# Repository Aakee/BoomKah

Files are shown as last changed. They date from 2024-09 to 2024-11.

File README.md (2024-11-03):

# Boom Kah
A *Keep Talking and Nobody Explodes* -inspired game with Arduino hardware.

Originally made for Hupsis-Punkku 2024 scouting competition.

## Overview

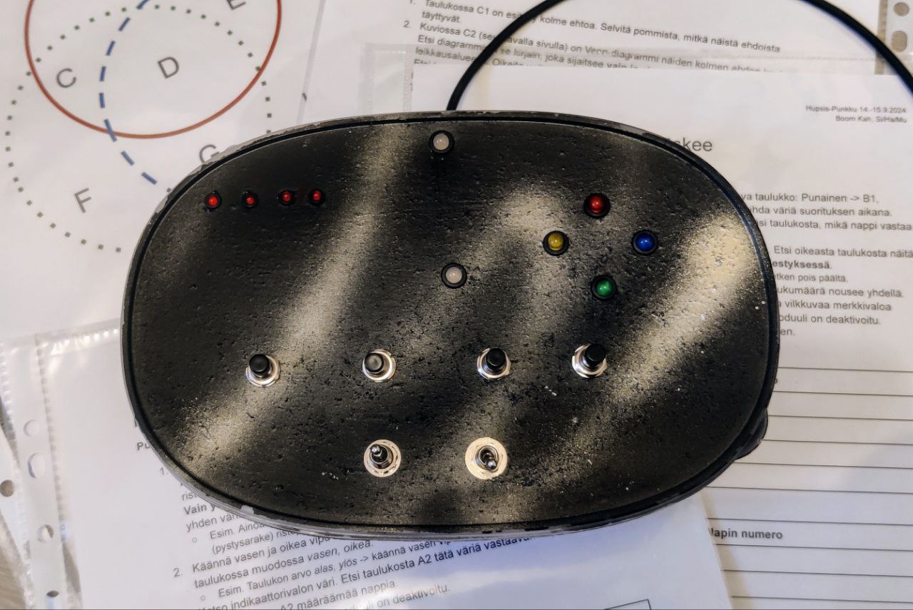
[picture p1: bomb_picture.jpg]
Bomb picture


Boom Kah is a game for two players. The objective is to co-operatively defuse a bomb, using a bomb defusal guide and the information given by the bomb.

The first player is a bomb defusal _Expert_. **The good news:** they have in hand all the information needed to defuse the bomb, in the form of a detailed Bomb Defusal Guide. **The bad news:** the bomb is not handled by them but by the second player, a total _Novice_ to bombs, who just happened to be in the wrong place in the wrong time (i.e. in a room with a bomb). 

Using voice as their only form of communication, the two players must communicate their through the bomb's modules, and hopefully not exploding in the process.

## Playing the game

### Defusal manual

Fear not, as the Expert has the access to the extensive Bomb Defusal Guide! The Guide is found in /docs, or [here](/docs/Pomminpurkuohjeet.pdf). For Expert eyes only -- the Novice is not allowed to see the manual while playing the game!

The Guide is only in Finnish for now.

### The Bomb

Below is a schematic figure and a photo of The Bomb.

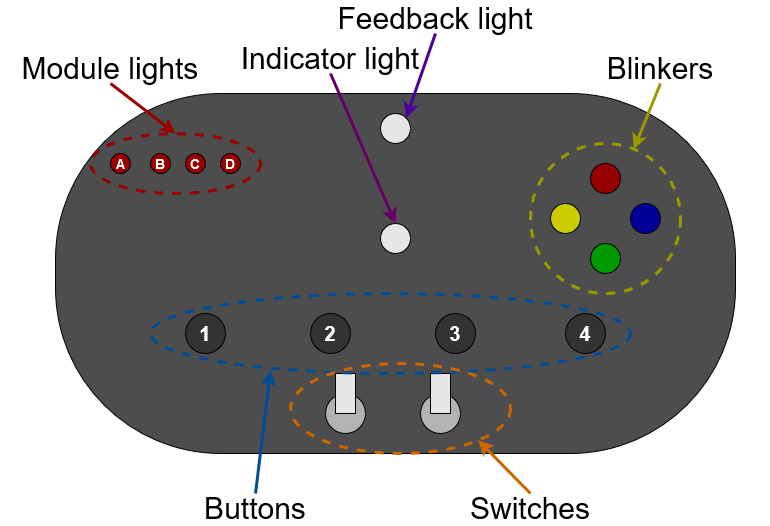
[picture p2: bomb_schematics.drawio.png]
Bomb schematics


The Bomb has four modules, each with their own set of deactivation rules. The current module to be deactivated can be determined by the **module lights**.

The Bomb gives information to the Novice in the form of **indicator light** and **blinker lights**. The Novice can then give commands to the bomb via the four buttons, conveniently called **buttons 1 - 4**, and two switches with three positions each, called **the left and the right switch**.

The Expert is not allowed to see The Bomb while playing. And while the Novice should only give such commands to The Bomb that the Expert reads from the manuals, it can happen that something is misunderstood... The Bomb gives feedback to the playes in the form of the **feedback light**: green light for correct actions, and red light for wrong actions. A high- or low-pitched beeping sound is also given alongside the feedback light: high for correct actions, and low for wrong actions.

The Bomb won't accept new commands while the feedback light is red. Initially, the time is rather short. However, this cooldown time gradually gets longer if the Novice gives too many incorrect inputs to the bomb.

### Defusing The Bomb

The modules must be deactivated one by one. The bomb is defused once all the modules have been deactivated. To mark this, the bomb plays a triple beeping sound, and the feedback light is turned green. Phew!

### Detonating The Bomb...?!?

As it is now, The Bomb does not actually explode (nor even simulate it). The goal of the players is to defuse the bomb as quickly as possible, but there is no maximum time, nor does the bomb explode even if incorrect inputs are given to the bomb. 

(But the players can give themselves some house rules, e.g. maximum time is 5 minutes, and the bomb explodes immediately after one incorrect input. Or they can experiment with the bomb and its modules and take all the time they need. Whatever suits the players best!)

## Software and hardware

The game is programmed with C++ enhanced with Arduino libraries. At the heart of the Bomb is a Arduino Nano (or a suitable clone).

List of the electrical components and schematics of the electorics can be found in /hardware.

## Credits

Akseli Konttas 2024

## Licence

MIT License, included in this repository

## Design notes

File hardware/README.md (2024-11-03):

# Boom Kah - hardware

## Arduino

The device was designed and built for Arduino Nano. For the actual production, [Seeeduino Nano](https://wiki.seeedstudio.com/Seeeduino-Nano/) was used instead. All the coupling diagrams and software should work with Arduino Nano or any equivalent Arduino clone, though.

## PCB

No PCB was made for this version; rather, the components were soldered straight to the Seeeduino pins with the help of a bread board.

## Components

The following describes other components used in the project. The codes refer to the codes shown in the coupling diagram.

### Buttons
Codes: B1B, B2B, B3B, B4B

Opening push button (circuit is closed when the button is not pressed, and open when the button is pressed). If you use closing push button, you need to modify the code accordingly in switch_handler.cpp.

### Switches
Codes: SW1, SW2

Switches with three positions: on-off-on.

### Module leds
Codes: DMOD1, DMOD2, DMOD3, DMOD4

Standard 3mm RED LEDs.

### Blinker leds
Codes: DBLNKRED, DBLNKGRN, DBLNKBLU, BBLNKYLW

Standard 5mm LEDs with differing colors (red, blue, green, yellow).

### Indicator led (RGB)
Code: DRGB

A common anode RGB LED.
If you use a common anode RGB, you need to make the following changes:

- Couple the common foot (anode) of the RGB to ground instead of 5V
- Change the polarity in rgb_handler.cpp: now the colours are set as '255-value'. Change them to be just 'value'.

### Feedback LED (RG)
Code: DRG

A common cathode red-green LED.

### Piezo loudspeaker
Code: BZ1

### Resistors

The LEDs have one series resistor to limit the currency and, by extension, the LED brightness of each LED. The values were found empirically so that each LED would shine with a suitable brightness. If using some other LEDs, you may need to change the values of these.

- Module LEDs: 1 kohm (each)
- Red blinker LED: 1 kohm
- Green blinker LED: 10 kohm
- Blue blinker LED: 5 kohm
- Yellow blinker LED: 680 ohm
- RGB: 200 ohm (each)
- RG: 200 ohm (each)

The buttons and swithces have the following pull-up and pull-down resistors:

- Buttons 1-4: 10 kohm pull-up resistor (each)
- Switches 1 and 2: 10 kohm pull-down resistor (each), and 10 kohm pull-up resistor (each).

The piezo loudspeaker has ha 200 ohm resistor in series.

Refer to the coupling diagram for better view on the usage and function of each resistor.

## Pin layout

Refer to the coupling diagram for resistors and other coupling details.

- D0: Module led B
- D1: Module led A
- D2: Module led C
- D3: Module led D
- D4: Red blinker
- D5: RGB red
- D6: Green blinker
- D7: Blue blinker
- D8: Piezo loudspeaker
- D9: RGB blue
- D10: RGB green
- D11: Yellow blinker
- D12: RG green
- D13: RG red
- A0 - A3: Buttons 1 - 4
- A4 - A5: Switches 1 and 2
- A6: Unconnected; initialization of the random seed

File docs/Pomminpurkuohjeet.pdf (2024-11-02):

Hupsis-Punkku 14.-15.9.2024 Boom Kah, Si/Ha/Mu

# Pomminpurun yleisohjeet

Pommissa on neljä moduulia, jotka pitää purkaa yksi kerrallaan, järjestyksessä A-B-C-D. Pommista löytyy yksi moduulivalo jokaista moduulia kohti, ja aktiivinen, tällä hetkellä purettava moduuli selviää palavasta moduulivalosta. Alla on kuva, jossa on eritelty pommin eri osat.

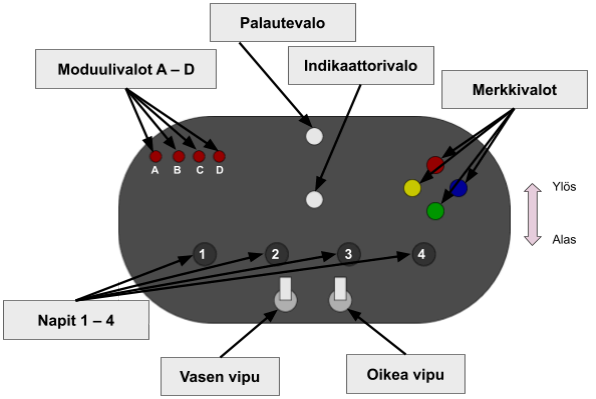
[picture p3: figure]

Purkuohjeet:
1. Katso, minkä moduulin valo palaa. Avaa oikean moduulin deaktivointiohjeet ja seuraa niitä.
- Merkkinä oikeista purkutoimenpiteistä pommi päästää korkeita piippauksia, ja palautevalo välähtää vihreänä.
- Merkkinä vääristä purkutoimenpiteistä pommi päästää matalan virheäänen, ja palautevalo syttyy punaisena. Pommi ei ota vastaan uusia komentoja, ennen kuin palautevalo on taas sammunut. Toistuvat virheet pidentävät aikaa, jona palautevalo palaa punaisena virheen jälkeen. Palautevalon sammuttua, jatka oikean moduulin deaktivointiohjeiden seuraamista.
2. Kun moduuli on deaktivoitu, kuulet kaksinkertaisen piippauksen ja seuraavan moduulin moduulivalo syttyy. Avaa tämän moduulin ohjeet ja seuraa niitä.
3. Kun kaikki moduulit A-D ovat deaktivoituja, kuulet kolminkertaisen piippauksen, kaikki moduulivalot sammuvat, ja palautevalo syttyy palamaan vihreänä. Pommi on nyt purettu onnistuneesti.

# Moduuli A: Vivut

Purkuohjeet:

1. Yksi tai kaksi merkkivaloa palaa.
Kahden merkkivalon palaessa etsi taulukosta A1 näiden kahden valon värien risteyskohdasta vipujen asennot.
Vain yhden merkkivalon palaessa etsi taulukosta A1 se kohta, joka on tämän yhden värin risteyskohdassa sekä vaaka- että pystyriviltä.
- Esim. Ainoastaan sininen valo palaa -> etsi taulukosta sinisen (vaakarivi) ja sinisen (pystysarake) risteyskohta (alas, ylös).
2. Käännä vasen ja oikea vipu taulukon A1 määräämään asentoon. Vivut ovat taulukossa muodossa vasen, oikea.
- Esim. Taulukon arvo alas, ylös -> käännä vasen vipu alas ja oikea vipu ylös
3. Katso indikaattorivalon väri. Etsi taulukosta A2 tätä väriä vastaavan napin numero.
4. Paina taulukon A2 määräämää nappia.
5. Toista kohtia 1-4, kunnes moduuli on deaktivoitu.

Taulukko A1

Punainen | Sininen | Vihreä | Keltainen
Punainen | Ylös, ylös | Ylös, keskelle | Keskelle, ylös | Alas, keskelle
Sininen | Ylös, keskelle | Alas, ylös | Alas, alas | Keskelle, keskelle
Vihreä | Keskelle, ylös | Alas, alas | Keskelle, alas | Ylös, alas
Keltainen | Alas, keskelle | Keskelle, keskelle | Ylös, alas | Alas, alas

Taulukko A2

Indikaattorivalon väri | Painettavan napin numero
Punainen | 3
Sininen | 1
Keltainen | 2
Turkoosi | 3
Violetti | 4
Valkoinen | 4
Vihreä | 1
Indikaattorivalo ei pala | 2

# Moduuli B: Kapteeni käskee

Purkuohjeet:

1. Katso indikaattorivalon väri ja etsi alta sitä vastaava taulukko: Punainen -> B1, sininen -> B2, ja vihreä -> B3. Indikaattorivalo ei vaihda väriä suorituksen aikana.
2. Yksi merkkivalo vilkkuu. Katso kohdassa 1 etsimästäsi taulukosta, mikä nappi vastaa kyseistä merkkivaloa. Paina tätä nappia.
3. Nyt kaksi merkkivaloa vilkkuvat tietyssä järjestyksessä. Etsi oikeasta taulukosta näitä vastaavat napit, ja paina niitä vuorotellen oikeassa järjestyksessä.
- Sarja alkaa alusta siitä, kun kaikki valot ovat olleet hetken pois päältä.
4. Jokaisen onnistuneen sarjan jälkeen vilkkuvien valojen lukumäärä nousee yhdellä. Jatka vastaavaan tapaan kohdan 3 toistamista – jokaista vilkkuvaa merkkivaloa kohden paina valon väriä vastaavaa nappia – kunnes moduuli on deaktivoitu. Epäonnistumisen myötä lukumäärä putoaa takaisin yhteen.

Taulukko B1: Punainen indikaattorivalo
Merkkivalon väri | Napin numero
Punainen | 2
Sininen | 3
Vihreä | 1
Keltainen | 4

Taulukko B2: Sininen indikaattorivalo
Merkkivalon väri | Napin numero
Punainen | 1
Sininen | 4
Vihreä | 3
Keltainen | 2

Taulukko B3: Vihreä indikaattorivalo
Merkkivalon väri | Napin numero
Punainen | 4
Sininen | 1
Vihreä | 2
Keltainen | 3

# Moduuli C: Venn

Purkuohjeet:

1. Taulukossa C1 on esitelty kolme ehtoa. Selvitä pommista, mitkä näistä ehdoista täyttyvät.
2. Kuviossa C2 (seuraavalla sivulla) on Venn-diagrammi näiden kolmen ehdon kesken. Etsi diagrammista se kirjain, joka sijaitsee vain ja ainoastaan täyttyvien ehtojen leikkausalueella. Oikeita vaihtoehtoja on aina tasan yksi.
3. Etsi taulukosta C3 edellisen kohdan perusteella oikea kirjain ja sitä vastaavat toimenpiteet. Tee määrätyt toimenpiteet.
4. Toista kohtia 1-3, kunnes moduuli on deaktivoitu.

Taulukko C1

Ehto | Venn-diagrammin kuvio

Ainakin yksi valo palaa sinisenä (merkkivalo tai indikaattorivalo).

Ainakin kolme merkkivaloa palaa.

Indikaattorivalo palaa sinisenä tai vihreänä.

Taulukko C3

Kirjain | Toimenpide
A | Käännä vasen vipu alas ja oikea vipu ylös. Paina nappia 3.
B | Käännä vasen vipu keskelle ja oikea vipu alas. Paina nappia 2.
C | Käännä vasen vipu keskelle ja oikea vipu ylös. Paina nappia 3.
D | Käännä vasen vipu ylös ja oikea vipu keskelle. Paina nappia 1.
E | Käännä molemmat vivut alas. Paina nappia 4.
F | Käännä vasen vipu alas ja oikea vipu keskelle. Paina nappia 4.
G | Käännä molemmat vivut ylös. Paina nappia 2.
H | Käännä vasen vipu ylös ja oikea vipu alas. Paina nappia 1.

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
5.9.2

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
h, Si/

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
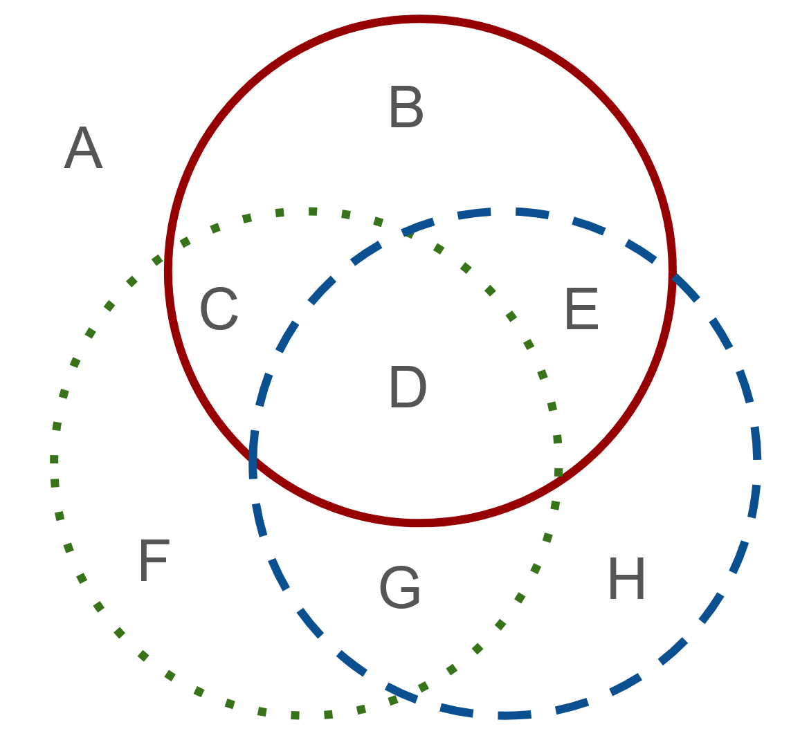
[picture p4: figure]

# Moduuli D: PIN-koodi

Purkuohjeet:

1. Etsi kokeilemalla sellainen asento vasemmalle ja oikealle vivulle, jossa kaikki neljä merkkivaloa palavat. Jätä vivut tähän asentoon.
2. Etsi taulukosta D1 rivi, joka vastaa vipujen asentoa. Katso tarvittava nelinumeroinen PIN-koodi samalta riviltä.
3. Syötä PIN-koodi laitteeseen seuraavasti:
- Paina ja pidä pohjassa koodin ensimmäistä numeroa vastaavaa nappia.
- Pitäen edellistä nappia pohjassa, paina seuraavaksi ja pidä pohjassa koodin toista numeroa vastaavaa nappia.
- Edelleen pitäen kahta edellistä nappia pohjassa, paina ja pidä pohjassa koodin kolmatta numeroa vastaavaa nappia.
- Viimeisenä, kolmen napin ollessa jo painettuna, paina ja pidä pohjassa koodin neljättä numeroa vastaavaa nappia. Kaikkien neljän napin pitäisi tässä vaiheessa olla painettuna.
4. Mikäli kuulet virheäänen ja palautevalo syttyy punaiseksi, päästä kaikki napit irti ja aloita uudelleen ohjeiden kohdasta 1. Muussa tapauksessa pidä kaikki napit painettuna, kunnes moduuli on deaktivoitu.

Taulukko D1

Vasemman vivun asento | Oikean vivun asento | PIN-koodi
Ylös | Ylös | 2 1 4 3
Ylös | Keskellä | 4 2 3 1
Ylös | Alas | 4 3 2 1
Keskellä | Ylös | 3 4 2 1
Keskellä | Keskellä | 2 3 4 1
Keskellä | Alas | 4 1 3 2
Alas | Ylös | 2 4 1 3
Alas | Keskellä | 3 1 2 4
Alas | Alas | 1 3 2 4

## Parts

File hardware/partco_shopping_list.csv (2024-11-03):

Name | Code | Quantity | Link
Opening push button | B1B, B2B, B3B, B4B | 4 | https://www.partco.fi/en/electromechanics/switches/push-button-switches/unlock-push-button-switches/7232-kyt-ava-mus.html
3-way switch | SW1, SW2 | 2 | https://www.partco.fi/fi/saehkoemekaniikka/kytkimet/vipukytkimet/pienet-vipukytkimet/26418-100-sp3-t100b1m1qe.html
Colour LED mix | DBLNKRED, DBLNKGRN, DBLNKBLU, DBLNKYLW, DMOD1, DMOD2, DMOD3, DMOD4 | 1 | https://www.partco.fi/fi/elektroniikan-komponentit/komponenttilajitelmat/26873-kit-ledbox.html
RGB LED | DRGB | 1 | https://www.partco.fi/fi/ledit/monivaeriledit/3576-ledrgb-5cad.html
RG LED | DRG | 1 | https://www.partco.fi/fi/ledit/monivaeriledit/20244-led-5pv3cc.html
Piezo loudspeaker | BZ1 | 1 | https://www.partco.fi/fi/audiovideo/kaiuttimet/10864-kaiutin-piezo.html

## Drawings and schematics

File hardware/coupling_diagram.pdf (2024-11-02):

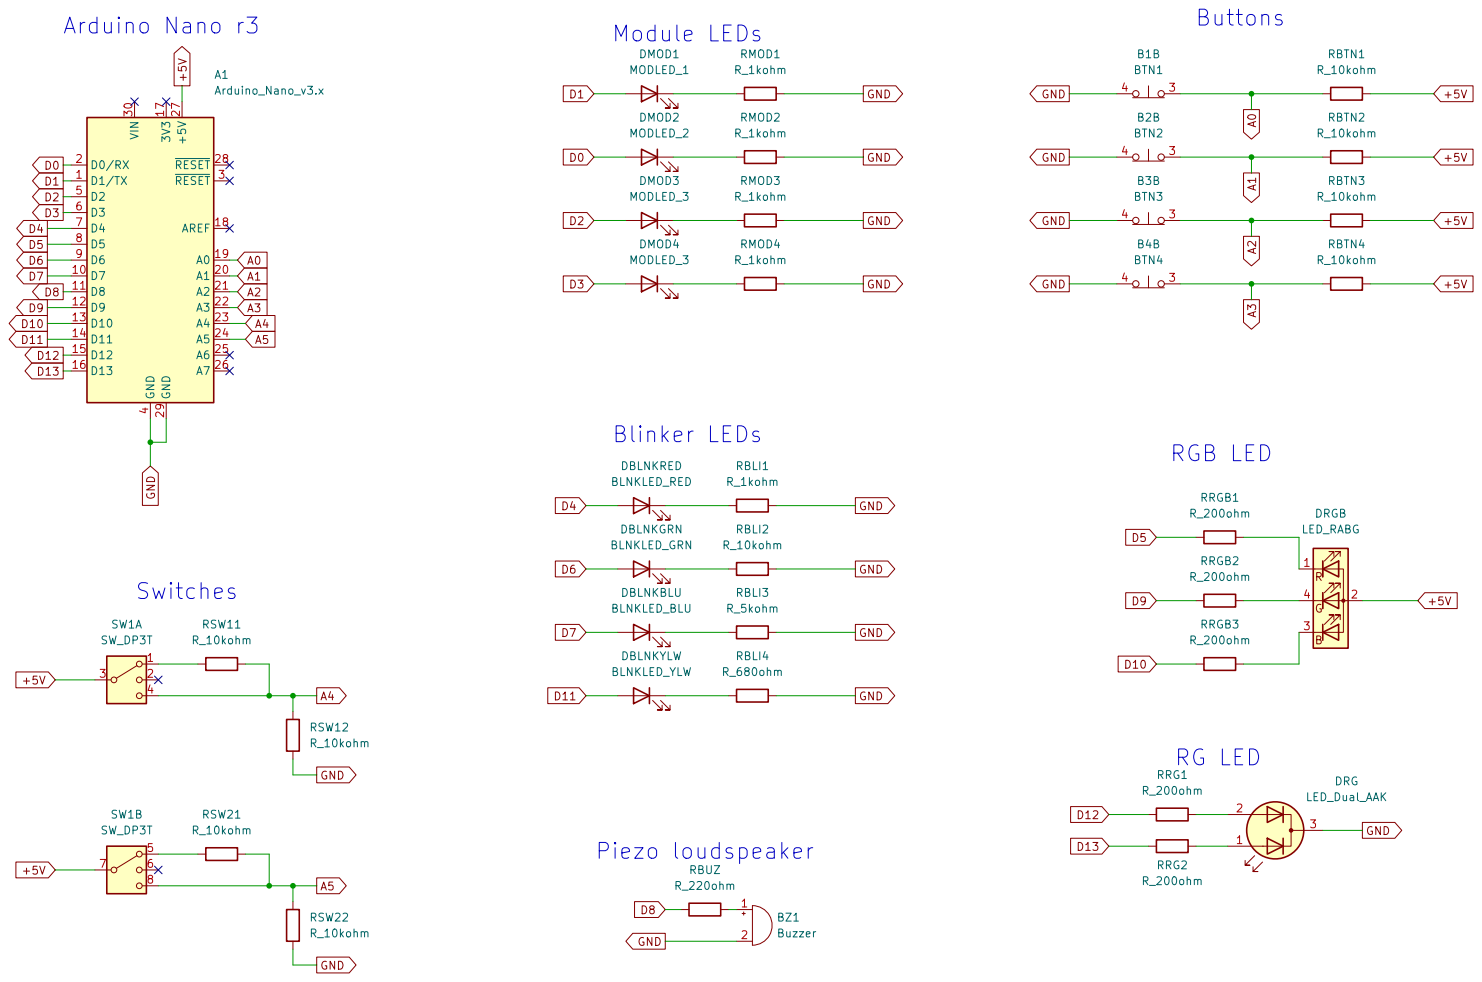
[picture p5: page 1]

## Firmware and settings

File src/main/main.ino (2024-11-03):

/*
    Main code for the Boom Kah - Keep Talking and Nobody Explodes -type game
    for Arduino Hardware.

    Refer for other documentation for wiring diagram and game rules.


    Author: Akseli Konttas 2024
*/

#include "switch_handler.h"
#include "module_led_handler.h"
#include "rgb_handler.h"
#include "blinker_handler.h"
#include "feedback_handler.h"
#include "Arduino.h"

#include "test_module.h"
#include "switches_module.h"
#include "pin_module.h"
#include "simon_module.h"
#include "venn_module.h"


// false --> always the same answers. true --> randomizes the proceedings
const bool RANDOMIZE = true;

// Enables 'easy mode' on some modules
const bool EASYMODE = true;

// Define pins for actuators

// Module LEDs
const int MOD_LED_1   = 1;
const int MOD_LED_2   = 0;
const int MOD_LED_3   = 2;
const int MOD_LED_4   = 3;

// Blinker LEDs
const int RED_LED    = 4;
const int GRN_LED    = 6;
const int BLU_LED    = 7;
const int YLW_LED    = 11;

// Buzzer
const int BUZ        = 8;

// RGB LED
const int RGB_RED    = 5;
const int RGB_BLUE   = 10;
const int RGB_GREEN  = 9;

// RG LED
const int RG_RED     = 13;
const int RG_GREEN   = 12;

// Buttons
const int BTN1       = A0;
const int BTN2       = A1;
const int BTN3       = A2;
const int BTN4       = A3;

// Switches
const int SWTCH1     = A4;
const int SWTCH2     = A5;


// Setup function
void setup() {
  //Serial.begin(9600);

  // Randomize the seed from an unconnected analog read pin
  randomSeed(analogRead(A6));
}


// The main loop
void loop() {

  // Define static objects (same for each loop)

  // Boolean telling if the game has been started yet
  static bool started = false;

  // Event and hardware managers
  static const auto switches         = SwitchHandler(BTN1, BTN2, BTN3, BTN4, SWTCH1, SWTCH2);
  static const auto moduleLeds       = ModuleLedHandler(MOD_LED_1, MOD_LED_2, MOD_LED_3, MOD_LED_4);
  static const auto rgb              = RGBHandler(RGB_RED, RGB_GREEN, RGB_BLUE);
  static const auto blinkers         = BlinkerHandler(RED_LED, GRN_LED, BLU_LED, YLW_LED);
  static const auto feedback         = FeedbackHandler(BUZ, RG_RED, RG_GREEN);

  // Modules, i.e. tasks for the players.
  //static const auto firstTask         = TestModule(RANDOMIZE);
  static const auto firstTask         = SwitchesModule(RANDOMIZE);
  static const auto secondTask        = SimonModule(RANDOMIZE);
  static const auto thirdTask         = VennModule(RANDOMIZE, EASYMODE);
  static const auto fourthTask        = PINModule(RANDOMIZE);

  // Tick the feedback light and sound, and see if the player is on cooldown
  bool canContinue = feedback.tick();
  if (!canContinue) {
    rgb.off(); blinkers.off(); return;
  }

  // Read and get button and switch states
  switches.read();
  SwitchStates* states = switches.get();

  // If not started, set default state
  if (!started) {
    feedback.red();
    if (states->btn1 || states->btn2 || states->btn3 || states->btn4) {
      feedback.off();
      started = true;
    } else {random();return;}
  }

  // Initialize module return value
  int success = 0;


  // Run through the first not-yet-completed task
  if (!firstTask.isCompleted()) {
    moduleLeds.set(1);
    success = firstTask.run(states, &rgb, &blinkers);
  }
  else if (!secondTask.isCompleted()) {
    moduleLeds.set(2);
    success = secondTask.run(states, &rgb, &blinkers);
  }
  else if (!thirdTask.isCompleted()) {
    moduleLeds.set(3);
    success = thirdTask.run(states, &rgb, &blinkers);
  }
  else if (!fourthTask.isCompleted()) {
    moduleLeds.set(4);
    success = fourthTask.run(states, &rgb, &blinkers);
  }
  
  // If the last module was just completed --> bomb defused, set blinkers off and send feedback
  if (success == 2 && fourthTask.isCompleted()) {
    rgb.off();
    blinkers.off();
    moduleLeds.off();
    feedback.bomb_defused();
  }

  // Otherwise, do actions based on the return value of the module
  else if (success ==  1) {feedback.correct();}
  else if (success ==  2) {feedback.module_deactivated();}
  else if (success == -1) {feedback.error();}

  // Advance the pseudo random number generator
  random();

}

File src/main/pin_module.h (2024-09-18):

#ifndef PIN_MODULE
#define PIN_MODULE

#include "switch_handler.h"
#include "rgb_handler.h"
#include "blinker_handler.h"
#include "feedback_handler.h"

/*
  Game module.
  Player finds a combination of left and right switch in which all four blinkers are lit, and based on
  the positions inserts a four-digit PIN code.
*/
class PINModule {

  public:

    // Creator and destructor
    PINModule(bool r = false);
    ~PINModule();

    // Main function
    int run(SwitchStates* switchState, RGBHandler* rgbHandler, BlinkerHandler* blinkerHandler);

    // Returns if this module has been succesfully completed or not
    bool isCompleted() {return completed;}

  
  private:

    // Member methods to help set the leds correctly
    void setBlinkers(BlinkerHandler*, SwitchStates*);
    void setRGB(RGBHandler*);

    // Member method to see if the current answer has been inserted correctly
    bool checkAnswer(SwitchStates*);

    // Randomizes the switches-blinkers-relationship if using randomized mode. (Does nothing if not using randomized mode.)
    void randomizeBlinkers();

    // Defaults
    int maxSuccessCount = 1;          // Changing this only applies to randomized mode

    // Internal variables
    bool completed                      = false;           // Tells if this module has been succcesfully completed or not
    int successCount                    = 0;               // Current number of passed rounds
    bool buttonsPreviouslyPressed[4]    = {false, false, false, false,}; // Button statuses of the previous iteration
    char currentBlinkers                = 0b0000;          // Current status of the blinkers
    int currentlyPressed[4]             = {0};             // Order in which the buttons were pressed
    bool shouldReset                    = true;           // true -> does not accept new presses until all buttons are released
    bool randomize;                                        // Whether to use randomized mode or not (set in initializer)

    // Maps the switch states to the correct pin codes. Every 4-integer sequence describes one such code.
    // Do not change! Otherwise the correct PIN codes from manual do not work.
    const int switches2pin[36] {
        1,3,2,4,    // down, down
        3,1,2,4,    // down, middle
        2,4,1,3,    // down, up
        4,1,3,2,    // middle, down
        2,3,4,1,    // middle, middle
        3,4,2,1,    // middle, up
        4,3,2,1,    // up, down
        4,2,3,1,    // up, middle
        2,1,4,3,    // up, up
    };

    // Maps the switch positions to blinker statuses: first three values are for first switch (down-middle-up),
    // and last three for the second switch (down-middle-up). The final blinkers are set with first + second.
    // The values here are also the default values, but they are changed during the runtime, if using randomized mode.
    int switches2blinkers[6] {
        0b1010,
        0b0100,
        0b0001,
        0b0101,
        0b0010,
        0b1000,
    };

};

#endif

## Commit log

2024-06-14 Added enumeration for switch state
2024-06-17 Added schematics for the project
    [kaboom.kicad_sch]
2024-06-18 SwitchHandler upgraded to v1.4
2024-06-19 Changed numbering of SwitchPosition
2024-06-19 Added SwitchesModule
2024-06-19 Fixed a bug in pin module
2024-06-19 Switch module can now behave randomly
2024-06-21 Fixed a incorrect PIN code in pin_module.h
    [pin_module.h]
2024-06-21 Corrected ifndef definition and added description to pin module
    [pin_module.h]
2024-06-23 All modules now disregard inputs given before first run of the module (if button is already pressed)
2024-07-06 Fixed typos in header include commands
    [pin_module.h, simon_module.h, switches_module.h]
2024-07-06 Added coupling diagram for the v1.4
    [kaboom.kicad_sch]
2024-07-06 Deleted old version of the schematics pdf
2024-09-12 Switched button polarity
2024-09-12 Modified RG led pins
2024-09-12 Switched RGB pins for blue and green
2024-09-12 Updated switch voltage-to-position mapping
2024-09-12 Implemented buffering for the buttons
2024-09-12 Changed the first round default blinker colors in switches module
2024-11-02 Updated coupling diagram
    [kaboom.kicad_sch]
2024-11-03 Added partco shopping list
    [partco_shopping_list.csv]
2024-11-03 Added white background to the schematics picture
